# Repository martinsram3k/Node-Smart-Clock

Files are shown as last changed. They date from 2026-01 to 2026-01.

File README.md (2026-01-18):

# Node Smart Clock

**Node Smart Clock** is an open-source, multi-functional desk clock powered by the **ESP32-WROOM-32D-N4**. It is designed as a central hub for makers, entrepreneurs, and crypto enthusiasts, combining advanced environmental sensing with real-time data tracking.

---

## Key Features

- **Environmental Monitoring:** Track CO2 levels, Air Quality (ENS160), and temperature in real-time.
- **Business & Crypto Tracker:** Live tracking for cryptocurrency prices, social media follower counts, and Shopify order notifications.
- **Smart Display:** 2.8" TFT display with **automatic brightness adjustment** based on ambient light (GY-302) to save battery.
- **Visual Notifications:** An array of **8 individually addressable LEDs** on top for animations, progress bars, and alerts.
- **Precise Timekeeping:** Dedicated **PCF8563T RTC chip** with a coin-cell backup, ensuring your alarms work even if the main power is lost.
- **Energy Efficient:** Optimized for **Deep Sleep** with a side-mounted **touch sensor** for intuitive wake/sleep control.

## Design & Construction

The project blends modern electronics with premium natural materials:

- [**3D Printed Chassis:**](https://github.com/martinsram3k/Node-Smart-Clock/tree/main/3d_models/stl) A minimalist housing designed for durability using **brass heat inserts**.
- **Hybrid Materials:** Front and back panels made of **real wood**, suitable for custom laser engraving.
- [**Custom PCB:** ](https://github.com/martinsram3k/Node-Smart-Clock/tree/main/pcb/esp_smart_clock)A professional-grade board integrating the ESP32-S3, 18650 battery charging.

## Hardware (BOM)

| Designator | LCSC # | Value / Description | Qty | Unit Price | Ext. Price | Note |
| --- | --- | --- | --- | --- | --- | --- |
| U1 | C473012 | ESP32-WROOM-32D-N4 | 1 | $3.78790 | $3.78790 | Main MCU |
| U4 | C15255 | PCF8563T (RTC) | 1 | $0.32000 | $0.32000 | Not in export, estimated |
| U5 | C6186 | AMS1117-3.3 (LDO) | 5 | $0.17350 | $0.86750 | Voltage regulator |
| U6 | C16581 | TP4056 (Charger) | 5 | $0.17840 | $0.89200 | Battery charging |
| D1-D8 | C22461793 | WS2812B (RGB LED) | 8 | $0.03840 | $0.30720 | Addressable LEDs |
| D10-D12 | C2128 | 1N4148WS (Diode) | 4 | $0.02100 | $0.08400 | Power OR Logic |
| Q1-Q4 | C318884 | S8050 (Transistor) | 10  | $0.01250 | $0.12500 | Reset/Motor/Buzzer |
| J1 | C2927039  | USB-C 16-pin | 1 | $0.23190 | $0.23190 | Power/Data |
| BT1 | C70381 | Battery Holder CR1220 | 1 | $0.13840 | $0.13840 | RTC Backup |
| C1, C2, C6 | C1525 | 100nF (0402) | 100 | $0.00130 | $0.13000 | Minimal order is 100pcs  |
| C3, C4, C5 | C13585 | 10uF (1206) | 10  | $0.02700 | $0.27000 | Power decoupling |
| x | x | 2.4 Inch TFT Display | 1 | $5.90000 | $5.90000 | Display |
| x | x | H7BC ENS160+AHT21 | 1 | $7.95000 | $7.95000 | Temp and co2 sensor |
| x | x | TTP223 | 1 | $0.07000 | $0.07000 | Touch sensor |
| x | x | BH1750 | 1 | $2.49000 | $2.49000 | Ambient light sensor |
| x | x | Brass Copper Embed Insert Nut | 8 | $0.04000 | $0.32000 | M3xL4xOD4.2 |

Download sheet for production: [Google sheets](https://docs.google.com/spreadsheets/d/1UgRSESd1yt6WZlXJIY08iRTUC7NtgjKNO3UkqPBUf44/edit?usp=sharing).

## Gallery






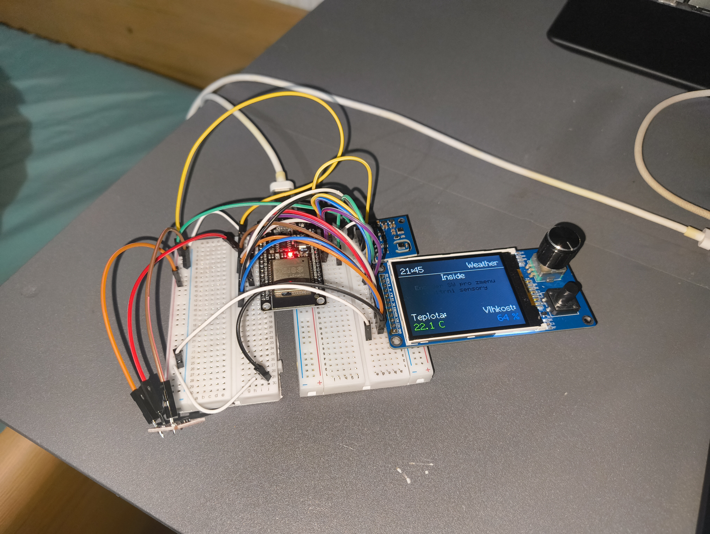
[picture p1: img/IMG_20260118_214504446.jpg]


## Software & Development

This project is fully **Open-Source**.

- **Framework:** Arduino IDE / PlatformIO.
- **Connectivity:** Integrated WiFi for NTP time sync and API data fetching.

---

## Support the Project

If you like the **Node Smart Clock**, there are several ways you can support the development:

<!-- * **MakerWorld Crowdfunding:** Support our campaign to help us scale PCB production and DIY kits! -->

- **Buy Me a Coffee:** Support my work directly at [buymeacoffee.com/martin.sram3k](https://buymeacoffee.com/martin.sram3k).
- **Follow My Journey:** Check out all my projects and social media via my [Linktree](https://linktr.ee/martin.sram3k).

Your backing helps us continue developing new open-source features and high-quality hardware for the community.

---

**License:** MIT – Feel free to share, modify, and build!

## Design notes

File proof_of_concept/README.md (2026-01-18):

# Node Smart Clock proof of concept

**Node Smart Clock proof of concept** is an proof of concept for my project node smart clock, its on bred board where i have esp32 dev board and H7BC ENS160+AHT21 sensor witch display and ttp touch button just to know if my vision is possible.

---

## Wiring diagram

### TFT display 
- GND -> esp32 GND
- VCC -> esp32 3.3
- SCL -> esp32 D18
- SDA -> esp32 D23
- RES -> esp32 D16
- DC -> esp32 D05
- CS -> esp32 D17
- BLK -> esp32 D04
- A -> esp32 D26
- B -> esp32 D27
- PUSH -> esp32 D14
- KO -> esp32 D25

### ENS160+AHT21 sensor
- 3.3 -> esp32 3.3
- GND -> esp32 GND
- SCL -> esp32 D22
- SDA -> esp32 D21
- ADD -> esp32 GND

### TTP223
- GND -> esp32 GND
- VCC -> esp32 3.3
- I/O -> esp32 D15

## Code

Link to code and libaries: [code](https://github.com/martinsram3k/Node-Smart-Clock/tree/main/proof_of_concept/code
).

## Gallery



## Support the Project

If you like the **Node Smart Clock**, there are several ways you can support the development:

<!-- * **MakerWorld Crowdfunding:** Support our campaign to help us scale PCB production and DIY kits! -->

- **Buy Me a Coffee:** Support my work directly at [buymeacoffee.com/martin.sram3k](https://buymeacoffee.com/martin.sram3k).
- **Follow My Journey:** Check out all my projects and social media via my [Linktree](https://linktr.ee/martin.sram3k).

Your backing helps us continue developing new open-source features and high-quality hardware for the community.

---

**License:** MIT – Feel free to share, modify, and build!

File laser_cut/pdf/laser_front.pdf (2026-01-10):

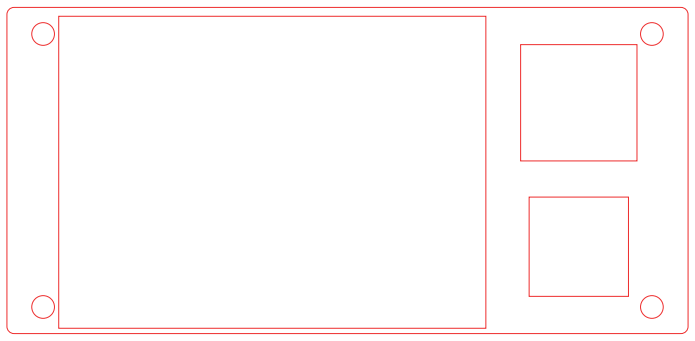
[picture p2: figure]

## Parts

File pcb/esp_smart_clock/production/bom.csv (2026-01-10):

Designator | Footprint | Quantity | Value | LCSC Part #
_6, _5, _4, _3, _2, |  | 6
C1, C2, C6 | C_0402 | 3 | 100nF | C1525
C3, C4, C5 | C_1206 | 3 | 10uF | C13585
D1, D3, D4, D5, D6, D7, D8, D9 | LED_WS2812B_PLCC4_5.0x5.0mm_P3.2mm | 8 | WS2812B | C22461793
D10, D11, D12, D2 | D_SOD-323 | 4 | 1N4148WS | C2128
IC1_2 | BAT-SMD_CR1220-2 | 1 | CR1220-2
IC1 | Battery_CR1225 | 1 | CR1220-2 | C70381
J1 | TYPE-C-SMD_HX-TYPE-C-16PIN | 1 | Connector, USB-TYPE-C-16P | C2927039
P1, P2, P3 | JST_PHR-2 | 3 | PHR-2 | C2319
Q1, Q2, Q3, Q4 | Q_SOT-23 | 4 | S8050 | C364312
R1, R12, R13, R2 | R_0402 | 4 | 10kΩ | C25744
R10, R11, R4, R5, R9 | R_0402 | 5 | 5.1kΩ | C25905
R3 | R_0402 | 1 | 100kΩ | C25741
R6, R7, R8 | R_0402 | 3 | 1.2kΩ | C25862
S1 | SW-SMD_4P-L5.1-W5.1-P3.70-LS6.5-TL-2 | 1 | Tactile Button, 160gf | C318884
U1 | MODULE_ESP32-WROOM-32D-N4 | 1 | ESP32-WROOM-32D-N4 | C473012
U2 | SOT-223-3_TabPin2 | 1 | AMS1117-3.3 | C6186
U3 | ESOP-8_L4.9-W3.9-P1.27-LS6.0-BL-EP | 1 | TP4056 | C16581
U4 | SOIC-8_L5.0-W4.0-P1.27-LS6.0-BL | 1 | PCF8563T | C7440
U8 | SSOP-10-1EP_3.9x4.9mm_P1mm_EP2.1x3.3mm | 1 | CH340K | C968586
X1 | FC-135R_L3.2-W1.5 | 1 | Q13FC1350000400 | C32346

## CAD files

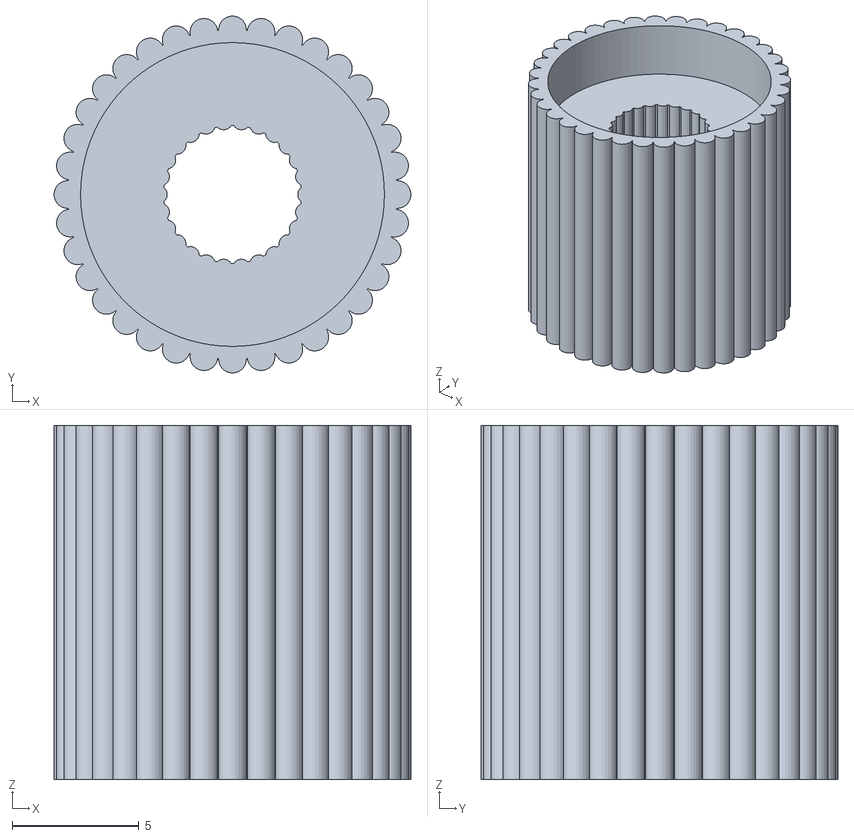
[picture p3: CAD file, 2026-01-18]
3d_models/stl/encoder_cap.stl
14.1 x 14.1 x 14.0

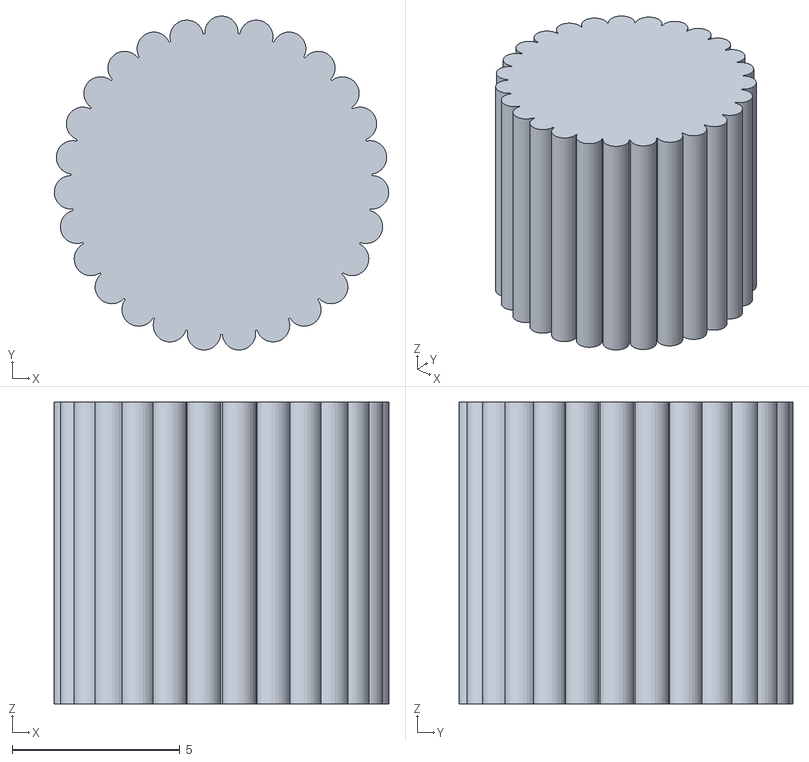
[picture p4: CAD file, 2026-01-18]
3d_models/stl/button_cap.stl
9.98 x 9.97 x 9.00

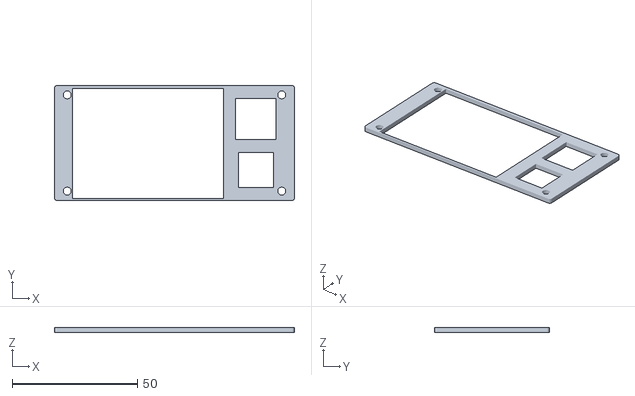
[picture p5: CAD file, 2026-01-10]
3d_models/stl/front_plate.stl
96.0 x 46.0 x 2.00

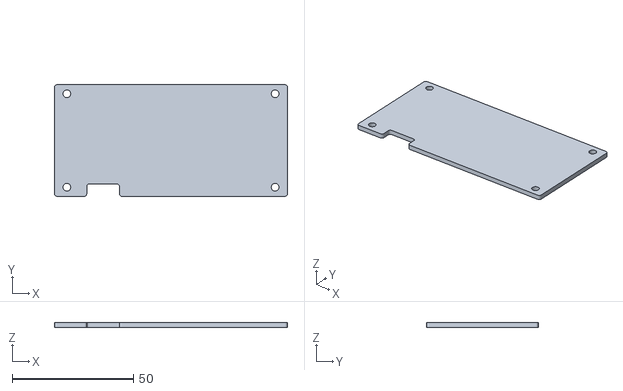
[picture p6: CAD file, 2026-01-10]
3d_models/stl/back_plate.stl
96.0 x 46.0 x 2.00

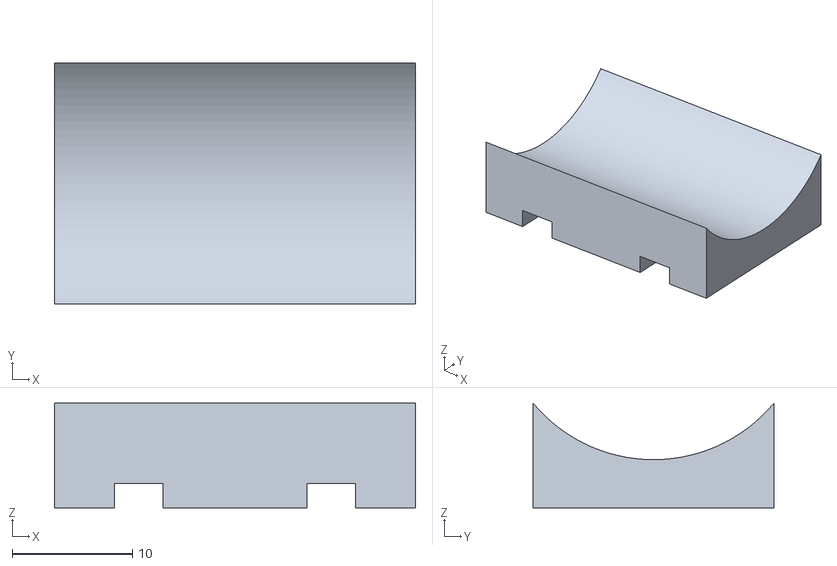
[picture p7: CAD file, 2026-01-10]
3d_models/stl/battery_hold.stl
30.0 x 20.0 x 8.69

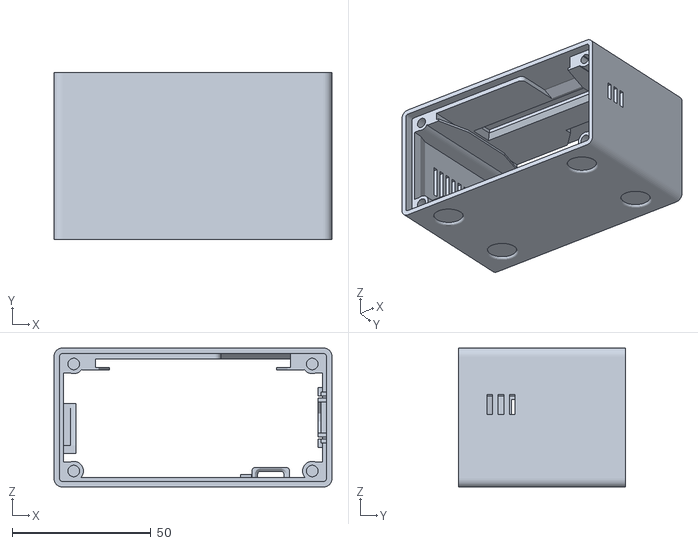
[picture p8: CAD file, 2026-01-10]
3d_models/stl/case.stl
100.0 x 60.0 x 50.0

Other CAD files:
3d_models/fusion/back_plate.f3d
3d_models/fusion/battery_hold.f3d
3d_models/fusion/button_cap.f3d
3d_models/fusion/case.f3d
3d_models/fusion/encoder_cap.f3d
3d_models/fusion/front_plate.f3d

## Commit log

2026-01-10 Update BOM and add new PCB autosave files
    Expanded the BOM table in README.md with detailed component information and pricing. Added new KiCad PCB autosave files and updated production backups and related CSVs for the esp_smart_clock project.
    [bom.csv, designators.csv, positions.csv]
2026-01-10 Update README and PCB files, add SD card subproject
    Updated the README with new ESP32 module info, BOM clarifications, and added a gallery section. Removed outdated PCB autosave and backup files, added new SD card KiCad project files, and updated main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
    [esp_smart_clock.kicad_pcb, esp_smart_clock.kicad_sch, sdcard.kicad_pcb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]
2026-01-16 Remove D2 diode and update net assignments
    Removed the D2 (1N4148WS) diode footprint from the PCB design and updated net assignments throughout the esp_smart_clock.kicad_pcb file to reflect the change. Also updated backup files and made minor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
    [assembely.f3z, esp_smart_clock.kicad_pcb, esp_smart_clock.kicad_sch]
2026-01-16 Add ENS160 Adafruit library and project scaffolding
    Introduced the ENS160 Adafruit Arduino library with source, examples, and documentation under proof_of_concept/code/lib. Added initial project structure including .gitignore, VSCode settings, platfor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
2026-01-17 Add ESP32Encoder library and update main.cpp
    Added the ESP32Encoder-master library to the project, including source, examples, and configuration files. Updated platformio.ini and main.cpp to integrate and utilize the new encoder functionality.
2026-01-17 Add weather API integration and sensor display
    Integrated OpenWeather API for outdoor temperature and humidity data, added Adafruit AHTX0 sensor support for indoor readings, and updated display logic to show current weather data based on 'inside'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
2026-01-17 Refactor main.cpp and update dependencies
    Added ENS160 air quality sensor integration and improved weather data handling in main.cpp. Updated platformio.ini to include ArduinoJson and reorganized build flags and dependencies. Enhanced displa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
2026-01-18 Add 3D and laser cut files for button and encoder caps
    Added Fusion 360 and STL files for button and encoder caps in the 3d_models directory. Also added Illustrator and PDF files for encoder cap in the laser_cut directory.
    [button_cap.f3d, button_cap.stl, encoder_cap.f3d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]
2026-01-18 Add wiring diagram and code link to README
    Added detailed wiring instructions for TFT display, ENS160+AHT21 sensor, and TTP223 modules. Included a link to the code repository for reference.
2026-01-18 Add links to 3D chassis and PCB sections in README
    Updated the README to include direct links to the 3D printed chassis and custom PCB folders, improving navigation for users seeking hardware resources.
2026-01-18 Remove vibration motor and buzzer from parts list
    Deleted the Mini Vibration Motor and Passive Buzzer entries from the README parts table, likely reflecting a change in the project's hardware requirements.
2026-01-21 Add ENS160 sensor integration and supporting libraries
    Introduced initial code and libraries for ENS160 sensor support, including custom and Adafruit-based drivers, example sketches, and supporting files for PlatformIO. Added .gitignore and VSCode config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
